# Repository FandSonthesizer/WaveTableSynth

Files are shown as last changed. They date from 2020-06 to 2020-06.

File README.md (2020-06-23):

# WaveTableSynth
This is a wavetable synth based on our Essential Shield project. It got midi, multiple voices, fm voices, ADSR and so on.
Based on the STM32 'Blue Pill' one can build this nice little gadget for less than 50€!

We added a 24dB VCF based on a Ray Wilson design (MusicFromOuterSpace) and got really good results. The VCF project is also included here.

Have fun building this project and even more fun to putting it to good use. :-)

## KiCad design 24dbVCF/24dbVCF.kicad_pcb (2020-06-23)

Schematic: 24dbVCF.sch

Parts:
C1, C5, C6, C7, C8: 100p; Kondensator_Keramik
C2, C3, C4, C9: 100n; Kondensator_Keramik
D1: 1N4148; D_DO-35_SOD27_P7.62mm_Horizontal
J1: CV1; Stift
J2: CV2; Stift
J3: CV3; Stift
J4: Audio1; Stift
J5, J6: Audio2; Stift
J9: Out; Stift
P1: 100k; Trimmer_Vertical
Q1, Q2: 2N3904; TO-92_Wide
Q3, Q4, Q5, Q6: 2N3906; TO-92_Wide
R1: 75k; Widerstand_liegend
R2, R3, R4, R5, R14, R17, R24, R27, R30, R33, R36, R39, R42, R43: 100k; Widerstand_liegend
R6: 7.5k; Widerstand_liegend
R7, R44: 2k; Widerstand_liegend
R8: 475; Widerstand_liegend
R9: 47k; Widerstand_liegend
R10: 68k; Widerstand_liegend
R11, R21, R28, R34, R40: 10k; Widerstand_liegend
R12: 1M; Widerstand_liegend
R13, R23: 39k; Widerstand_liegend
R15, R25, R31, R37: 100; Widerstand_liegend
R16, R26, R32, R38: 20k; Widerstand_liegend
R18, R19, R20: 200k; Widerstand_liegend
R22: 300k; Widerstand_liegend
R29, R35: 43k; Widerstand_liegend
R41: 4.7m; Widerstand_liegend
T1: 100; Trimmer_Vertical
U1, U4: TL072; DIP-8_W7.62mm_Socket_LongPads
U2, U5: LM13700; DIP-16_W7.62mm_Socket_LongPads
U3: TL074; DIP-14_W7.62mm_Socket_LongPads

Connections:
+12V: P1.1, R12.2, R16.2, R26.2, R32.2, R38.2, U1.8 (V+), U2.11, U3.4 (V+), U4.8 (V+), U5.11; also elsewhere on the board
-12V: R1.1, R13.1, R23.1, R29.1, R35.1, U1.4 (V-), U2.6, U3.11 (V-), U4.4 (V-), U5.6; also elsewhere on the board
GND: C5.1, C6.1, C7.1, C8.1, Q2.2, Q3.1, Q4.1, Q5.1, Q6.1, R8.1, R15.1, R25.1, R31.1, R37.1, R41.1, R42.1, U1.3 (+), U1.5 (+), U2.3, U2.14, U4.3 (+), U5.3, U5.14; also elsewhere on the board
unnamed: C1.1, R9.1, R10.2, R11.2, U1.7
unnamed: C1.2, Q1.3, R12.1, U1.6 (-)
unnamed: C2.1, J4.1
unnamed: C2.2, R18.2
unnamed: C3.1, J5.1
unnamed: C3.2, R19.2
unnamed: C4.1, J6.1
unnamed: C4.2, R20.2
unnamed: C5.2, U2.12, U3.5 (+)
unnamed: C6.2, U2.5, U3.10 (+)
unnamed: C7.2, U3.12 (+), U5.12
unnamed: C8.2, U3.3 (+), U5.5
unnamed: C9.1, R39.1, U3.1, U3.2 (-)
unnamed: C9.2, R41.2, U4.5 (+)
unnamed: D1.1, R9.2, R10.1
unnamed: D1.2, Q1.2, T1.2
unnamed: J1.1, R3.2
unnamed: J2.1, R4.2
unnamed: J3.1, R5.2
unnamed: J9.1, R44.1
unnamed: P1.2, R2.2
unnamed: P1.3, R1.2
unnamed: Q1.1, Q2.1, R11.1
unnamed: Q2.3, Q3.2, Q4.2, Q5.2, Q6.2
unnamed: Q3.3, R21.2
unnamed: Q4.3, R28.2
unnamed: Q5.3, R34.2
unnamed: Q6.3, R40.2
unnamed: R2.1, R3.1, R4.1, R5.1, R6.2, R7.2, U1.2 (-)
unnamed: R6.1, R7.1, T1.1, U1.1
unnamed: R8.2, T1.3
unnamed: R14.2, R22.1, U4.1
unnamed: R16.1, U2.15
unnamed: R17.1, R24.2, U3.6 (-), U3.7
unnamed: R18.1, R19.1, R20.1, R22.2, U4.2 (-)
unnamed: R21.1, U2.16
unnamed: R23.2, R24.1, R25.2, R27.2, U2.4
unnamed: R26.1, U2.2
unnamed: R27.1, R30.2, U3.8, U3.9 (-)
unnamed: R28.1, U2.1
unnamed: R29.2, R30.1, R31.2, R33.2, U5.13
unnamed: R32.1, U5.15
unnamed: R33.1, R36.2, U3.13 (-), U3.14
unnamed: R34.1, U5.16
unnamed: R35.2, R36.1, R37.2, R39.2, U5.4
unnamed: R38.1, U5.2
unnamed: R40.1, U5.1
unnamed: R42.2, R43.2, U4.6 (-)
RA: R43.1, R44.2, U4.7; also elsewhere on the board
RB: R13.2, R14.1, R15.2, R17.2, U2.13; also elsewhere on the board

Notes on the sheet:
Cutoff Freq
Tempco
Scale
Match all PNP's
Matched Pair
Audio Mixer Out

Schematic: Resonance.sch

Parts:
C10, C11, C12, C13, C14, C15, C16, C17, C18, C19, C20, C21, C22, C23, C24, C25: 100n; Kondensator_Keramik
C26, C27: 10u; Elko_D6.3mm_P2.50mm
J7: Res; Stift
J8: Conn_02x08_Odd_Even; PinHeader_2x08_P2.54mm_Vertical
P2: 100k; Trimmer_Vertical
R45, R46: 49.9k; Widerstand_liegend
R47, R48, R50, R51, R53: 100k; Widerstand_liegend
R49, R56: 120k; Widerstand_liegend
R52, R54, R58, R59: 30k; Widerstand_liegend
R55: 200k; Widerstand_liegend
R57: 1k; Widerstand_liegend
R60: 4.7k; Widerstand_liegend
R61: 150k; Widerstand_liegend
U6, U7: TL072; DIP-8_W7.62mm_Socket_LongPads
U8: LM13700; DIP-16_W7.62mm_Socket_LongPads

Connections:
+12V: C10.1, C12.1, C14.1, C16.1, C18.1, C20.1, C22.1, C24.1, C26.1, J8.9, J8.10, R45.1, U6.8 (V+), U7.8 (V+), U8.11; also elsewhere on the board
-12V: C11.2, C13.2, C15.2, C17.2, C19.2, C21.2, C23.2, C25.2, C27.2, J8.1, J8.2, R46.1, R51.2, R60.1, U6.4 (V-), U7.4 (V-), U8.6; also elsewhere on the board
GND: C10.2, C11.1, C12.2, C13.1, C14.2, C15.1, C16.2, C17.1, C18.2, C19.1, C20.2, C21.1, C22.2, C23.1, C24.2, C25.1, C26.2, C27.1, J8.3, J8.4, J8.5, J8.6, J8.7, J8.8, R52.1, R57.1, R59.1, U6.3 (+), U7.3 (+), U7.5 (+), U8.4, U8.13, U8.14; also elsewhere on the board
unnamed: J7.1, R48.2
unnamed: P2.1, R45.2
unnamed: P2.2, R47.2
unnamed: P2.3, R46.2
unnamed: R47.1, R48.1, R49.2, U6.2 (-)
unnamed: R49.1, R50.2, U6.1
unnamed: R50.1, R53.2, U6.6 (-)
unnamed: R51.1, R52.2, U6.5 (+)
unnamed: R53.1, R58.2, U6.7
unnamed: R54.1, R56.2, U7.2 (-)
unnamed: R55.1, R57.2, U8.3
unnamed: R55.2, R56.1, U7.1
unnamed: R58.1, U8.1
unnamed: R59.2, U8.5, U8.7
unnamed: R60.2, R61.2, U8.8
unnamed: U7.6 (-), U7.7
RA: R54.2; also elsewhere on the board
RB: R61.1; also elsewhere on the board

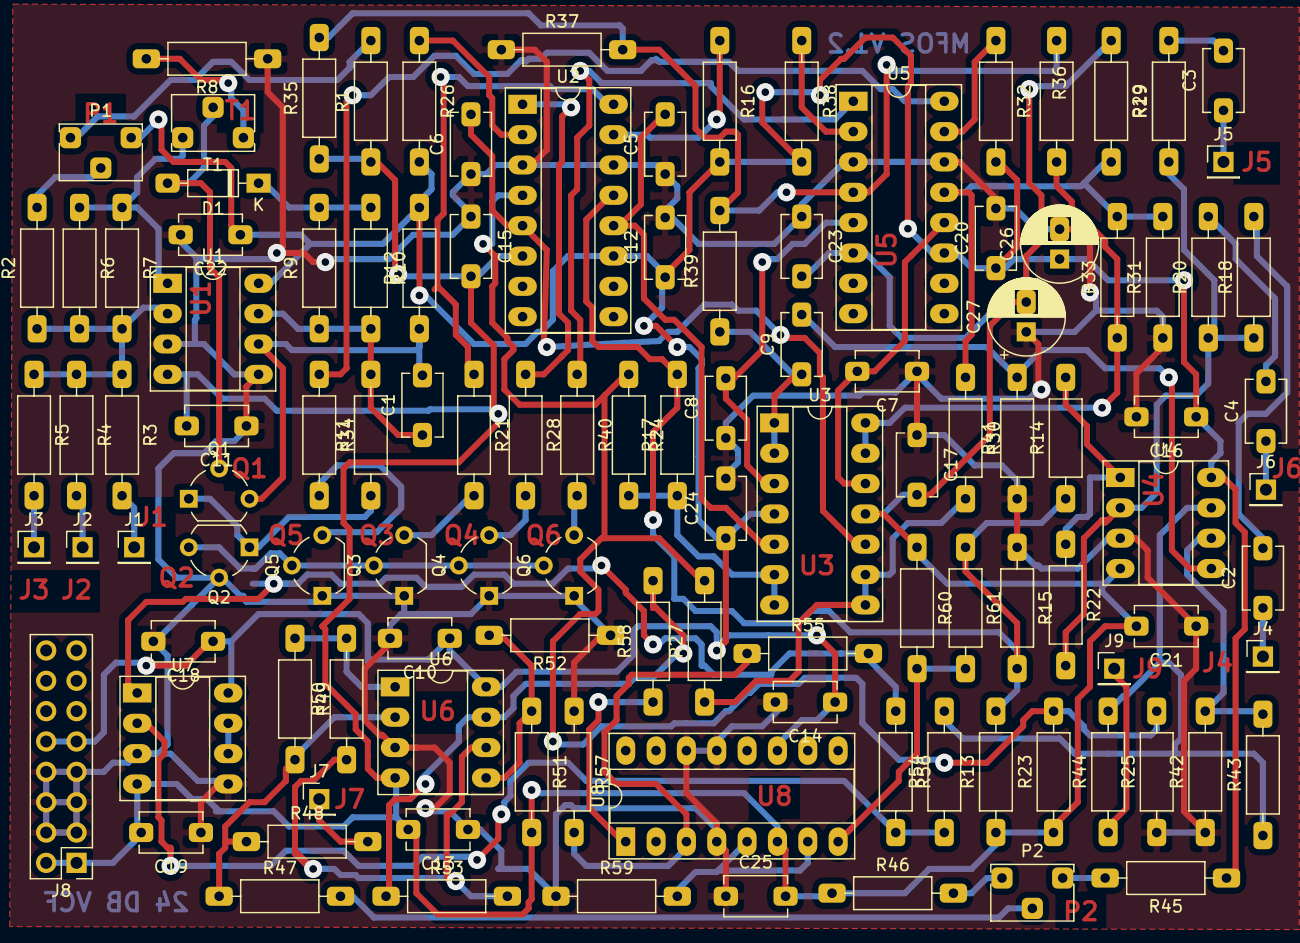
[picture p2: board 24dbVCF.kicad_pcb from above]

Board: 2 copper layers, 115 parts (0 on the bottom side), 69 nets.

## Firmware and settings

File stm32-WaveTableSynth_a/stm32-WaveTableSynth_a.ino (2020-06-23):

/**
 * Father & Sonthesizer (c) 2019
 * Wavetable Synthesizer V1.1
 * 
 * ToDO: keytracking, Effects
 * 
 *
 */
#include "NiksMidi.h"
#include "Voice.h" 
#include "Controls.h"
#include "Reverb.h" 
#include "Tune.h"
#include "EEPROM.h"

//--- !!!!!!!!!!!!!!!!!!!!!!!!!!!!!!!!!!!!!!!! ---------------
// #define USE_BOOTLOADER   // uncomment this, when using the stm32 bootloader, or else no Midi is possible

// #define USE_ATAN_MIX   //  Audio mixer methods, use just one!
#define USE_CLIP_MIX   //    

# if defined USE_ATAN_MIX   
  #include "Atan.h"  
#endif   
//----------- Pins ---------------
#define PWM_OUT       PA8    // PA8 PWM output pin, Audio out
#define PWM_OUT2      PA11    // PWM output pin, ADSR out
#define ONBOARDLED    PC13   //  
#define scalePin      PA2 //PA2    // freq tuning

int ypos = 18;
int zero = 0;

//---------Some debug values ----------------------
const bool doMidi = true;           // if true, the synth listens to midi in
const bool debug = false;           // If true, play a small melody as a test
const bool trigger = true;           // If true, use the encoder push button to trigger one midi note

const bool doReverbF = false;      // if true, actually use the build in reverb filter 
const bool doFilterADSR = true;    // if true, also generate the filter ad signal for external analog filter
const bool doADSR = true;          // if true, apply an ADSR to each midi note
const bool doScope = true;         // if true, show the actual playing waveform on the display 
//
const bool debugVoice = false;      // if true, the loop will calculate the voice engine. (Used for debugging)
const bool testRev = false;        // If true, just do a test of the reverb filter. (Used onyl for debugging)
const bool Align = false;          // if true  run max-output on pwm1 and pwm 2. use to align trimmer pots for output volume
//---
const uint16_t isr_cnt =  40;     // interrupt rate 25us = 40000
const uint16_t pwm_cnt =  20;     // pwm frew @ 50kHz , 10us=max ampl. 720 20us=max ampl. 1440

//MIDI_CREATE_DEFAULT_INSTANCE();
//using namespace midi;
//MIDI_CREATE_INSTANCE(HardwareSerial, Serial1, MIDI); 

const boolean LISTENTOALLCHANNELS = false;

//------------ Vars --------------
uint32_t mil = 0;               // millisec. tic, this replace the call: millis()
uint32_t globalTic = 0;           
//uint32_t potDebounce = 0;
int waveFormD[128];

bool start = true;                  // true, while we are in  start-mode
uint16_t testrun = 0;
bool testRuns = false;
bool play = debug;

String tmp = "";
uint32_t avgsumv = 0;     // experimantal lp filter on synth out, not used!
uint16_t mcountv = 0;
int16_t AVERAGEV = 64;

const int EEP_CHANNEL = 0;
const int WAVE_CHANNEL = 1;
const int DATTACK_CHANNEL = 2;
const int DDECAY_CHANNEL = 3;
const int PWM_CHANNEL = 4;
const int VSTART = 5;
const int VEND = 6;
const int FM_DECAY = 7;

int midiChannel = EEPROM.read(EEP_CHANNEL);        // Midi channel

// Tune, used to play a little tune, mostly needed for debugging
uint32_t tuneStart = 0;
int tuneIndex;
bool tunePlaying = false;
bool startTune = debug;
int tcnt;

/**
 * Debug voice
 */
bool startDebugVoice = debugVoice;
bool voiceDebugging = false;

// Vars for oszilloscope display:
int16_t vres = 0;
uint16_t dispIdx = 0, refreh = 0, anz = 0;
uint16_t tbase = 1; //
uint16_t tbaseidx = 0;
uint16_t DisplayScale = 4000;

//Analog input
uint16_t aChannel = 0;
uint16_t aDelayIDX = 0;
const uint16_t ADELAY = 50;

bool tstate = false;


byte sNo = 1;
//byte channel = EEPROM.read(WAVE_CHANNEL);        // Midi channel


/**
 * Setup routine, this is the first to be called on startup of the stm32
 */
void setup() {
  // 1st Initialize the programm
  sNo =  EEPROM.read(WAVE_CHANNEL); // 0=saw, 1=sin,2=tri, 3=sqr, 4=FM
  //sNo = 4; // saw debug
  if (sNo < 0 || sNo > 4) {
    sNo = 1;
     EEPROM.write(WAVE_CHANNEL, sNo);
  }
  fat =  EEPROM.read(DATTACK_CHANNEL); 
  fde =  EEPROM.read(DDECAY_CHANNEL);

  pwm_value = EEPROM.read(PWM_CHANNEL);
  if (pwm_value < 10 || pwm_value > 1020) {
    pwm_value = 512;
    EEPROM.write(PWM_CHANNEL, pwm_value);
  }
  pw = pwm_value;

  v_start =  EEPROM.read(VSTART);   
  if (v_start < 0 || v_start > 4096) {
       v_start = 256;
       EEPROM.write(VSTART, v_start);
  }
  v_end =  EEPROM.read(VEND);   
  if (v_end < 0 || v_end > 4096) {
       v_end = 64;
       EEPROM.write(VEND, v_end);
  }
  fm_decay =  EEPROM.read(FM_DECAY);   
  if (fm_decay < 0 || fm_decay > 4096) {
       fm_decay = 1023;
       EEPROM.write(FM_DECAY, fm_decay);
  }
  
  initControls();
  initVoices(doMidi);
  initGraphic();
  setAdsrVals(); // some values to beginn with. Maybe read from EEprom ?
  initRev(); // inít reverb filter
  requestToUpdate = true; // inital draw of the display
  if (midiChannel > 15) {
    midiChannel = 1;
    EEPROM.write(EEP_CHANNEL, midiChannel);
  }
  
  pinMode(ONBOARDLED, OUTPUT); // on - board led etc
  pinMode(scalePin, INPUT_ANALOG);
  /* Initialization of midi input and serial for debug*/
 /* if (doMidi) {
    MIDI.setHandleNoteOn(handleNoteOn);  // Put only the name of the function
    MIDI.setHandleNoteOff(handleNoteOff);  // Put only the name of the function
  }
  */
  if (doMidi){
    
    # if defined USE_BOOTLOADER   
      Serial1.begin(31250);//31250
    #elif !defined USE_BOOTLOADER
      //HardwareSerial Serial2(PA3, PA2);   // or HardWareSerial Serial2 (PA3, PA2);
      Serial.begin(31250);   //31250 
    #endif   
    
  }
 else 
    Serial.begin(115200);
    // init oled display 
    display.begin(SSD1306_SWITCHCAPVCC);
    display.display();
    // Clear the buffer.
    display.clearDisplay();
  
    # if !defined USE_BOOTLOADER  
      while (!Serial) { // this does not seem to work on my blue-pill, Serial is always true...
        delay(10);      // and with the boot-loader the pill stm never leaves this loop!
     }
    #endif
  
  /**
  * Pwm Set for analog out: 50kHz, 0-1420
 */
  HardwareTimer timer1 = HardwareTimer(1);  // using timer 1, can be 2,3,4...
  timer1.setPrescaleFactor(1);              // Pre-scale factor 1-65536
  timer1.setPeriod(pwm_cnt); //0-1420 @ 50kHz    // microseconds uSec 
  pinMode(PWM_OUT, PWM);      // synthesizer analog output

/**
  * Pwm Set for analog out: 50kHz, 0-1420
 */
  HardwareTimer timer3 = HardwareTimer(3);  // using timer 1, can be 2,3,4...
  timer3.setPrescaleFactor(1);              // Pre-scale factor 1-65536
  timer3.setPeriod(pwm_cnt); //0-1420 @ 50kHz    // microseconds uSec 
  pinMode(PWM_OUT2, PWM);   // Filter AD output

  /** 
   *  Setup Timer 2 to 25u (40000 per second)
   */
  Timer2.setMode(TIMER_CH1, TIMER_OUTPUTCOMPARE);
  Timer2.setPeriod(isr_cnt);                          // in microseconds (25u)
  Timer2.setCompare(TIMER_CH1, 1);                   
  if (!testRev && !debugVoice) 
    Timer2.attachInterrupt(TIMER_CH1, handler_Synth);   // in this routine the synth moves through the wave-table

  /**
   * Really only used when I developed this effect...
   */
  if (testRev) {
      // init the reverb-filter
      Serial.println("Start Rev test");
      setDelayTime(100); // [0-4096] = 0-120ms
      // Fill buffer with a small ramp
      for (int n = 0; n < 50; n++)
        writeHead(n);
      //delay(1000);
  }
  
  //---
  selectWave(sNo); // 1 = sin
  //displayPage0(midiChannel, sNo); // start screen
  
 // dispChannel(midiChannel, 0);
 // sei(); //Enable interrupt
 
  digitalWrite(ONBOARDLED, 1); // turn LED off
  delay(200);
}



void loop() {
  readMIDI();   // my own, very basic, midi in Method
  //MIDI.read();

  /**
   * Only on start-up 
   */
  if (mil > 1000 && start) {
    if (!doMidi)
      Serial.println("Wavetable Synth v1.0");
    setAdsrVals();
    /**
     * output full amplitude to align the low pass filter gain
     */
    if (Align) {
      Serial.println("Start Alignment");
      pwmWrite(PWM_OUT, 1420);
      pwmWrite(PWM_OUT2, 1420);
    }
    /*Serial.print("fat=");
    Serial.print(fat);
    Serial.print(" fde=");
    Serial.println(fde);
    */
    start = false;
    testrun = 0;
  }

/**
 * Start method, Just for debugging a voice
 */
  if (startDebugVoice) {
      startDebugVoice = false;
      Serial.println("Start debug Voice");
      setAdsrVals();
      tuneStart = 0; // time-stamp
      dispIdx = 0;
      handleNoteOn(1, 65, 127); // just start one note, not using the interrupt routine. (Just for debugging)
      display.clearDisplay();
      voiceDebugging = true;
  }
   
   updateDisplay();
   
//----
/**
 * True, if a voice is being debugged
 */
  if (voiceDebugging) { // to debug the synth voice engine, no interrupt used
    doVoice();
    tuneStart++;
    if (vAdsr[0].ADSR_mode == STOPPING) {
      voiceDebugging = false; // stop
    }
    else if (tuneStart > 40000) {
      handleNoteOff(1, 38, 0); 
    }
  }
  else if (testRev) {
    doReverb();   // test the reverb filter, no interrupt used. (so we can print debug info)
  }
  else if (startTune) { // if request to play
    startTune = false;
    startPlayTune(); // reset Index and start first note
  }
  
  if(tunePlaying) {
    playTune();
  }
  
  // -------- release notes in end of release state for re-use ------
  /**
   * If a voice is in finished release state mode (STOPPING), just clean it up here.
   * If we would do this in the interrupt routine, unexpected things might happen! :-)
   */
  for (int n=0; n < MAXVOICE; n++) {
   if (vAdsr[n].ADSR_mode == STOPPING) {
    int nt = voice[n].note;
    voice[n].note = 0;
    vAdsr[n].ADSR_mode = STOP;
   /* Serial.print(n);
    Serial.print(" CTRL Loop Free Note");      
    Serial.print(nt);
    Serial.print(" @");      
    Serial.print(n);
    */
   }
  }
  
  /**
   * Here now we read the periphal adjustment components, 
   *  like potentiometers etc.
   */
   //int Nscale = adc_read(ADC2, PA0);       // ADC2 read noisy voltage value from pot.
   /*Serial.print("Attack=");
   Serial.println(Nscale);
   */
   aDelayIDX++;
   if (aDelayIDX > ADELAY) {
     aDelayIDX = 0;
     readAnalogChannel(aChannel);
     aChannel++;
     if (aChannel >= MAXPOT)
       aChannel = 0;
   }
   actOnEncoder(mil);

  if (trigger) {
    if (readInputPin(mil, ENCODERBT)) {
      // button state has changed
      if (buttons[ENCODERBT].lastButtonState == 0) {
        // pressed
        //Serial.println("Button Pressed");
        if (page == DATTACK || page == DDECAY) {
          if (page == DATTACK )
            page = DDECAY;
          else
            page = DATTACK;  
          requestToUpdate = true;
        }
        else 
          handleNoteOn(1, 62, 127); 
      }
      else {
        //Serial.println("Button Released");
        if (page != DATTACK && page != DDECAY) {
          handleNoteOff(1, 62, 0);
        }
      } 
    }
  }
}

void readAnalogChannel(int n) {
  if (start)
    return; // not in start mode...
  
   bool change = updateAnalogChannel(n);
   if (change) { 
      if (n == P_ATTACK){
        setAttackScale(Avalue[n], VOICES);
        setAtValue(Avalue[n]); // for the graphic 
       // Serial.print("Attack=");
       // Serial.println(Avalue[n]);
      }
      else if (n == P_DECAY){
        setDecayScale(Avalue[n], VOICES);
        setDeValue(Avalue[n]);
      }
      else if (n == P_SUSTAIN){
        setSustainValue(Avalue[n], VOICES);
        setSusValue(Avalue[n]);
      }
      else if (n == P_RELEASE){
        //Serial.print("Release=");
       // Serial.println(Avalue[n]);
        setReleaseScale(Avalue[n], VOICES);
        setReValue(Avalue[n]);
      }
      else if (n == P_REVDELAY){
        setDelayTime(Avalue[n]); // 0-250ms
      }
      /*else if (n == P_PWM){
        pwm_CValue = Avalue[n] >> 2;  // : 4, analog = 0-4095 to 0-1023 PWM Value
        //setReleaseScale(Avalue[n], VOICES);
      }
      */
       else if (n == P_MODUL){
        setFMModulator(Avalue[n]); // 0-2048
      }
      
     // page = 1; // if button is pressed?
     // drawADSR();
    }
}


void actOnEncoder(uint32_t mil) {
  
  if(readEncoder(mil)) {
    // encoder pos was changed
    /*Serial.print("Encoder=");
    Serial.print(encoderPosCount);
    Serial.print(" direction=");
    Serial.println(bCW);
    */
    readInputPin(mil, SHIFT);
    if (buttons[SHIFT].lastButtonState == 0) { 
      // shift is pressed, we are in page select mode
      // change menu tab
      if (bCW) {
        page++;
        if (page > PAGEMAX)
          page = PAGEMAX;
      }
      else {
        page--;
        if (page < 0)
          page = 0;
      }
      if (page == SCOPE)
        display.clearDisplay();
      requestToUpdate = true;
    }
    else {
      // we are in value-select mode
      if (page == WAVESEL) {
        // select a new waveform!
        if (bCW) {
          sNo++;
          if (sNo > WMAX)
            sNo = WMAX -1;
        }
        else {
          sNo--;
          if (sNo < 0)
            sNo = 0;
        }
        Serial.print("Waveform=");
        Serial.println(sNo);
        EEPROM.write(WAVE_CHANNEL, sNo);
        selectWave(sNo);
      }
      else if (page == BASE) {
        if (bCW) {
          midiChannel ++;
          if (midiChannel > 15)
            midiChannel = 15;
        }
        else {
          midiChannel--;
          if (midiChannel < 1)
            midiChannel =1;
        }
         EEPROM.write(EEP_CHANNEL, midiChannel);
      }
      else if (page == DATTACK) {
        if (bCW) {
          fat += 200;
          if (fat > 4095)
            fat = 4095;
        }
        else {
          fat -= 200;
          if (fat < 10)
            fat =10;
        }
        setAttackScale(fat, FILTER);
        EEPROM.write(DATTACK_CHANNEL, fat);
      }
      else if (page == DDECAY) {
        if (bCW) {
          fde += 200;
          if (fde > 4095)
            fde = 4095;
        }
        else {
          fde -= 200;
          if (fde < 10)
            fde = 10;
        }
        setDecayScale(fde, FILTER);
        EEPROM.write(DDECAY_CHANNEL, fde);
      }
      else if (page == DPWM) {
        if (bCW) {
          pwm_value += 50;
          if (pwm_value > 1020)
            pwm_value = 1020;
        }
        else {
          pwm_value -= 50;
          if (pwm_value < 10)
            pwm_value = 10;
        }
        pw = pwm_value;
        EEPROM.write(PWM_CHANNEL, pwm_value);
      }
      else if (page == FMSTART) {
        if (bCW) {
          v_start += 10;
          if (v_start > 2048)
            v_start = 2048;
        }
        else {
          v_start -= 10;
          if (v_start < 10)
            v_start = 10;
        }
        //pw = pwm_value;
        EEPROM.write(VSTART, v_start);
      }
      else if (page == FMEND) {
        if (bCW) {
          v_end += 10;
          if (v_end > 2048)
            v_end = 2048;
        }
        else {
          v_end -= 10;
          if (v_end < 10)
            v_end = 10;
        }
        //pw = pwm_value;
        EEPROM.write(VEND, v_end);
      }
      else if (page == FMDECAY) {
        if (bCW) {
          fm_decay += 20;
          if (fm_decay > 2048)
            fm_decay = 2048;
        }
        else {
          fm_decay -= 20;
          if (fm_decay < 10)
            fm_decay = 10;
        }
        //pw = pwm_value;
        EEPROM.write(FM_DECAY, fm_decay);
      }
      requestToUpdate = true;
    }
  }
}
/**
 * Init ADSR default values to default values, maybe from eeprom?
 */
void setAdsrVals() {
  //Serial.println("Set ADSR values");
    setDelayTime(4000); // 
    Avalue[P_REVAMOUNT] = 4000;
    setAttackScale(20, VOICES);
    setAtValue(20);
    setDecayScale(600, VOICES);
    setDeValue(600);
    setSustainValue(2048, VOICES);
    setSusValue(2048);
    setReleaseScale(200, VOICES);
    setReValue(200);

    // AD Filter setting
    setAttackScale(fat, FILTER);
    setFAtValue(fat);
    setDecayScale(fde, FILTER);
    setFDeValue(fde);
    /*setAttackScale(400, FILTER);
    setFAtValue(400);
    setDecayScale(600, FILTER);
    setFDeValue(600);
    */
    setSustainValue(0, FILTER); // not used
    setReleaseScale(100, FILTER);// not used
}

/**
 * Set reverb amount mix value
 * @param a value of the mix pot [0-4095]
 */
void setRevAmount(uint16_t a) {
  // To be done
}

//------------------------------------------------------------------------------------------

/**
 * Interrupt routine, triggered every 25us (40Khz)
 * In this routine, we travel along the wavetable and output the amplitude values we find.
 */
 void handler_Synth(void) {
  globalTic++;            // count up all the time at 40khz
  if (globalTic > 39) {
    globalTic = 0;        // 40 tics at 40 khz is one millisec.
    mil++;                // increase millisecond tic, used for button debounce etc.
  }
  doVoice();              // the actual sound generation
 }




/**
 * Just for debugging, not used in synth!
 */
 void doReverb() {
  // Reverb: ---------- make echo switchable? Or just set 0
    if (delayTime > 0 && diff == 0) {
      uint16_t rv = readRev(); // echo value
      Serial.print("readPointer=");
      Serial.print(readPointer);
      Serial.print(" v=");
      Serial.print(rv);
      Serial.print(" writePointer=");
      Serial.println(writePointer);
    }
    else if (diff > 0) {
      Serial.print("Buffering diff=");
      Serial.print(diff);
      Serial.print(" writePointer=");
      Serial.println(writePointer);
    }
      
    writeHead(1); // write empty 
 }

//-------------------------------

 void handleAllNoteOff() {
   for (int n=0; n < MAXVOICE; n++) {
     if(voice[n].note > 0){
         setGateOff(n); // change adsr state
     }
   }
 }
  
/**
 * Command received from Midi, stop a voice
 * velocity ignored for the moment...
 */
 void handleNoteOff(byte inChannel, byte inNote, byte inVelocity) {
  //dispNoteOff(inNote, 0);
  if (midiChannel == inChannel || LISTENTOALLCHANNELS) { // all notes
     // Midi Off
       int slot = findOldestMidiNote(inNote);
       if (slot < 0) {
       // Serial.print("Error for note ");
       // Serial.println(inNote);
        return;
       }
       if (!doMidi) { 
        Serial.print(slot);
        Serial.print(" -Off ");
        Serial.print(inNote);
        Serial.print(" @");
        Serial.print(voice[slot].activationTime);
        Serial.print(" Now:");
        Serial.println(mil);
       }
       setGateOff(slot); // change adsr state
       /*if (!doScope) {
          dispNoteOff(inNote, slot);
       }
       */
    }
    
 }

/**
 * A note on signal was read either from MIDI or from the tune-player
 */
void handleNoteOn(byte inChannel, byte inNote, byte inVelocity) {
    //dispNoteOn(inNote, 0);
    //Serial.print("handleNoteOn nt=");
    //Serial.println(inNote);

    /**
     * Repect the Midi channel ?
     */
    
    if (midiChannel == inChannel || LISTENTOALLCHANNELS) {
      int slot = -1;
      for (int n=0; n < MAXVOICE; n++) {
         if(voice[n].note == 0){
             slot = n;
             break;
         }
      }
      if (slot < 0) {
         // no voice found to use!
         //Serial.println("On: No empty slot found!");
         int oldestSlot = -1;
         // find the oldest note
         uint32_t maxT = 0xffffffff;
         uint32_t maxRT = 0xffffffff;
         for (int n=0; n < MAXVOICE; n++) {
           if (voice[n].activationTime < maxRT &&  vAdsr[slot].ADSR_mode == RELEASE) {
             maxRT =  voice[n].activationTime;
             slot = n; // oldest slot already in Release state
           }
           else if (voice[n].activationTime < maxT) {
             maxT = voice[n].activationTime;
             oldestSlot = n; // oldest note
            // Serial.print("On: actual oldest ");
             //Serial.println(slot);
           }
         }
         // now use the oldest release slot or the oldest slot
         if (slot < 0)
            slot = oldestSlot;
      } 
      vAdsr[slot].ADSR_mode = STOP;
      voice[slot].activationTime = mil;
      
      if (!doMidi) {
          Serial.print(slot);
          Serial.print(" +On ");
          Serial.print(inNote);
          Serial.print(" @");
          Serial.println(voice[slot].activationTime);
      }
      // now trigger the new voice
    
      uint16_t f = getFreq(inNote); // determine freq. from midi note
      if (waveForm != FM)
          setVoiceFreqency(f, slot, mil); // set the step value for the isr
      else
          setFMFrequencys(f, slot, mil);
      voice[slot].note = inNote;
      setGateOn(slot); // start adsr, gate on setGateOn(channel); // start adsr, gate on
      /*if (!doScope) {
        dispNoteOn(inNote, slot);
      }
      */
   }
}

void  print(String s, int val) {
  Serial.print(s);
  Serial.println(val);
}
// -------------------

/**
 * Find an active playing midi note in the voices array
 * @param note the note to look for
 * @return the voice-index or -1 if not found
 */
int16_t findOldestMidiNote(uint16_t note) { 
 // Serial.print("Find oldest Note to turn off n=");
 // Serial.print(note);
  
  int16_t slot = -1;
  uint32_t oldestTime = 0xffffffff; // highest 32 bit number
  for (int16_t n = 0; n < MAXVOICE; n++) {
      if (voice[n].note == note) {
        if (vAdsr[n].ADSR_mode > STOP &&  vAdsr[n].ADSR_mode < RELEASE ) {
          if (voice[n].activationTime < oldestTime) {
            slot = n;
            oldestTime = voice[n].activationTime;
          }
        }
      }
   }
  // Serial.print(" Resulting slot=");
  // Serial.println(slot);
  return slot; 
}
//----------------------------------------


  //--------------
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

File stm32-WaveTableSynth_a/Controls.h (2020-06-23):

// Ky-040 encoder
const int ky_clk  = PB14;   // Connected to CLK on KY-040
const int ky_dt   = PA12;   // Connected to DT on KY-040
//const int ky_sw   = PA15;   // Der Switch wird mit Pin D2 Verbunden. 



const uint16_t MAXPOT  = 7;
const uint16_t P_ATTACK  = 0;
const uint16_t P_DECAY  = 1;
const uint16_t P_SUSTAIN  = 2;
const uint16_t P_RELEASE  = 3;
const uint16_t P_REVDELAY  = 4;
const uint16_t P_REVAMOUNT  = 5;
//const uint16_t P_PWM  = 6;
const uint16_t P_MODUL  = 6;

const int AVERAGE =       16;     // For the gliding average method (LP filter for noisy analog values)

uint16_t pin[MAXPOT];             // Analog input pins
uint16_t mcount[MAXPOT]; // 
uint32_t avgsum[MAXPOT]; 
uint16_t Avalue[MAXPOT];  // 0-4096, analog in

// Encoder vars:
uint32_t TimeOfLastDebounce = 0;
uint16_t DelayofDebounce = 10;
int16_t encoderPosCount = 0; 
uint16_t dtVal_Old = 1;
boolean bCW;

//Switches & buttons
const int noOfButtons = 4;
const uint16_t ENCODERBT  = 0;
const uint16_t SHIFT  = 1;
const uint16_t SW1  = 2;
const uint16_t SW2  = 3;

typedef struct {
  int portPin;                 // Pin Nunber to read;
  uint16_t debounceDelay;      // debounceDelay = 50;    // the debounce time; increase if the output flickers
  uint16_t lastDebounceTime;   // lastDebounceTime = 0;  // the last time the output pin was toggled
  uint16_t lastButtonState;    // actual state
 } Button_type;
Button_type buttons[noOfButtons];

void initControls() {
  // define and init input pins:
  buttons[ENCODERBT].portPin  = PA15;
  buttons[SHIFT].portPin      = PB5;
  buttons[SW1].portPin        = PB6;
  buttons[SW2].portPin        = PB7;
  
  for(int n = 0; n < noOfButtons; n++) {
    buttons[n].debounceDelay = 100;
    buttons[n].lastDebounceTime = 0;
    buttons[n].lastButtonState = 1;             // not pressed
    pinMode(buttons[n].portPin, INPUT_PULLUP);
  }
  // Define the analog input pins: 
  pin[P_ATTACK] = PA0;
  pin[P_DECAY] = PA1;
  pin[P_SUSTAIN] = PA2;
  pin[P_RELEASE] = PA3; //pa3
  
  pin[P_REVDELAY] = PA6;
  pin[P_REVAMOUNT] = PA7; // mix

  pin[P_MODUL] = PA4; // generic 1 fm modulator

  for (int n = 0; n < MAXPOT; n++) {
     mcount[n] = 0;
     avgsum[n] = 0;
     Avalue[n] = 0;
     pinMode(pin[n], INPUT_ANALOG);
  }
}

/**
 * Gliding Average value.
 * This method simulates a capacitor to even out the noisyness of the stm32's adc.
 * @param newval the ne value, read from adc
 * @param potCh which channel to read
 */
uint32 glidingAverage(uint16 newval, uint16 potCh) {
   uint32 average = 0; 
   if (mcount[potCh] < AVERAGE) { // initial loading of the capacitor
      avgsum[potCh] += newval;
      average = avgsum[potCh] / mcount[potCh];
      mcount[potCh]++;
   }
   else {
    // now hold and change the charge
      avgsum[potCh] -= avgsum[potCh] / AVERAGE;
      avgsum[potCh] += newval;
      average = avgsum[potCh] / AVERAGE;
   }
   return average;
}

/**
 * read an analog channel. Store value in Avalue[potCh]
 * @param potCh the analoge channel to read
 * @return true if the value was changed
 */
bool updateAnalogChannel(uint16 potCh) {
   // Read the Potentiometer value 
   bool c = false;
   /*Serial.print("Channel=");
   Serial.print(potCh);
   */
   int Nscale = adc_read(ADC2, pin[potCh]);       // ADC2 read noisy voltage value from pot.
   //Serial.print(" Nscale=");
  // Serial.print(Nscale);
   uint32 m = glidingAverage(  Nscale, potCh );   // Add the new adc value into a gliding average value
   //Serial.print(" GAverage=");
  // Serial.print(m);
   uint32 d = abs(m - Avalue[potCh]);
   //Serial.print(" diff=");
   //Serial.println(d);
   if (d > 5) {
      Avalue[potCh] = m;
      c = true;
   }
   return c;
}
// ----------- switches amd buttons: -------------------------
/**
 * @param btn number of the button/switch
 * @return true if changed
 */
boolean readInputPin(uint32_t mil, int btn) {
  // Reset Button:
    bool res = false;
    uint16_t bt = digitalRead(buttons[btn].portPin); // 0=clear, 1 = neutral
   // Serial.println(bt);
    uint32_t diff = mil - buttons[btn].lastDebounceTime;
    //  Serial.println(diff);
    if (buttons[btn].lastButtonState != bt && diff > buttons[btn].debounceDelay ) {
      if (bt == LOW) {
        // pressed
          buttons[btn].lastDebounceTime = mil;
        }
    }
    res = buttons[btn].lastButtonState != bt;
    buttons[btn].lastButtonState = bt; // here we save the actual button state
   /*if (bt == 0)
      Serial.println("Shift pressed");
      */
    return res;
}

bool readEncoder(uint32_t mil) {
  int inc = 1;
  int dtVal = digitalRead(ky_dt);
  bool change = false;
  unsigned long diff = mil - TimeOfLastDebounce;
  if (dtVal != dtVal_Old && diff > 10 && dtVal == 0) {
    // falling flank on dt !
    bCW = digitalRead(ky_clk) == 1;
    (bCW)?encoderPosCount +=inc: encoderPosCount -=inc;
      TimeOfLastDebounce = mil; 
      change = true;
  }
  dtVal_Old = dtVal;
  return change;
}
